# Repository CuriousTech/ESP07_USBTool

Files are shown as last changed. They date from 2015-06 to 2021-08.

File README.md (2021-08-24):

# ESP07_USBTool
3-in-1 board for ESP-07/12

[Clone from BangGood using spring clips](https://www.banggood.com/ESP8266-Test-Board-Burner-Development-Board-WIFI-Module-For-ESP-01-ESP-01S-ESP-12E-ESP-12F-ESP-12S-ESP-18T-p-1684992.html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)

USB powered with FTDI for programming and testing.  
Leave the FTDI and supporting components off for standalone USB 5V powered or 3.5-6V using pads on bottom rear.  
Use as serial+3V3 breakout with 0.1" pads for header on top rear of board.  
  
Rev 1.  Pogo pins are optional.  Outer 4 pinholes are for hold downs and should be done last for adjusting.  Get the height of the outer pins above inner, but only less that the size of the PCB.  
  
deepSleep is the R9 resistor  
run is R10   

esp07tool  

For more on the pogo-pins.  Lineup was done using all 3 PCBs and spacers.  Paste on top and heatgun.  

tool pogos

tool pogos 2

tool pogos 3

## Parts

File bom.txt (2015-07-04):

3V3R    MCP1824ST-3302E/DB (6V 300mA 0.3Vdo)
        TC1262-3.3VDBTR (6V 500mA 0.3Vdo)
        MCP1755T-3302E/DC (16V 300mA 0.5Vdo)
        MIC2920A-3.3WS TR (26V 400mA 0.75Vdo) Change C1 to 10uF.

IC1     FT230X-SSOP16
R1,R2   27 0805
R3      10K 0805  (reset pullup, don't use with deepSleep)
R4      10K 0805  (CH_PD pullup)
R5-R8   330 0805
R9      1K or jump (deepSleep)
R10     1K or jump (RUN enable)
C1,C2   1uF 0805
C3,C4   0.1uF 0805
C5,C6   47pF 0805
FLASH,RESET 3x4x2mm SMD button (eBay)
USB f   10118193-0001LF
LEDs    4x 0805 any color
JP1,JP2, top serial BO  breakable header 18 pins 0.1" + 1 jumper
ESP-07  Anywhere
P50-E2  0.68mm pogo pins (20) (eBay)

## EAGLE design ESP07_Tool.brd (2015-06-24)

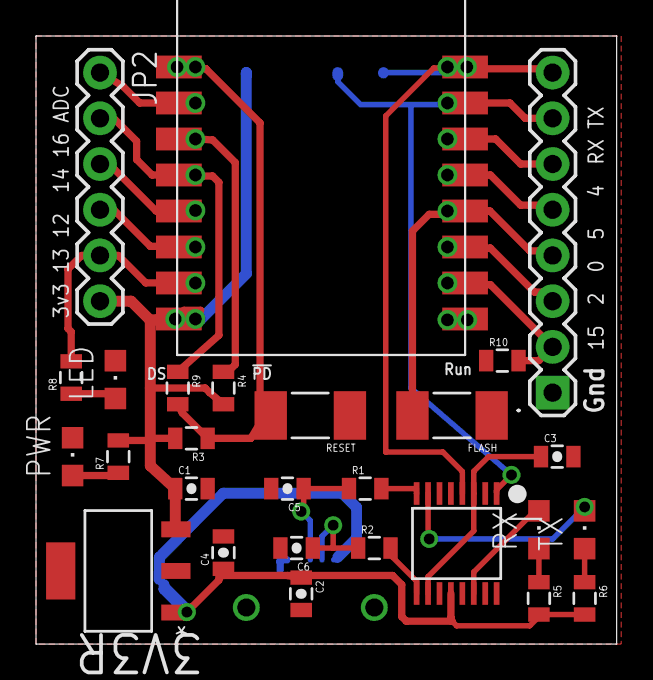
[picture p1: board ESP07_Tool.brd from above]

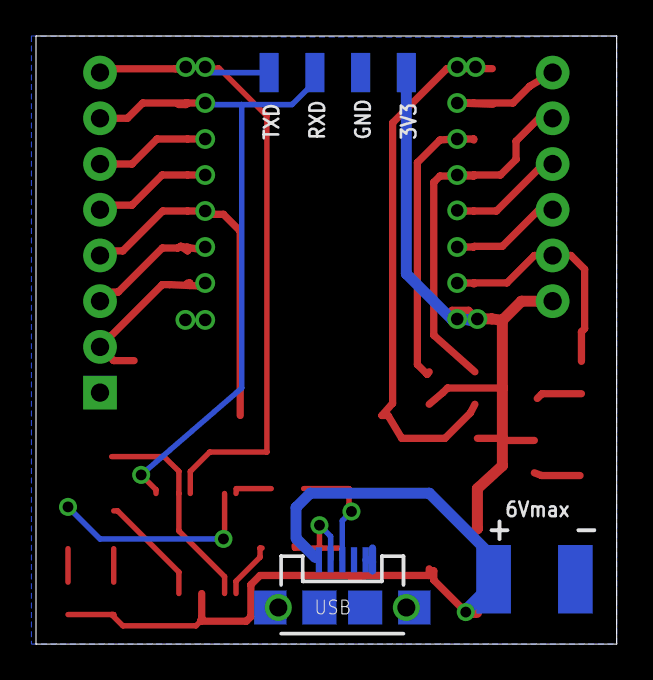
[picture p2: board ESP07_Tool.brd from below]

Board: 2 copper layers, 32.3 x 33.8 mm, 34 parts (7 on the bottom side), 28 nets.

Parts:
3V3R: MCP1824ST-3302E/DB; SOT230P700X180-4N
.: 1X08
C1, C2: 1uF; 0805-CAP
C3, C4: 0.1uF; 0805-CAP
C5, C6: 47pF; 0805-CAP
FLASH: R2010
JP2: 1X06
LED: CHIPLED_0805
PWR: CHIPLED_0805
R1, R2: 27; 0805
R3, R4, R9, R10: 10K; 0805
R5, R6, R7, R8: 330; 0805
RESET: R2010
RX: CHIPLED_0805
TX: CHIPLED_0805
U$1: ESP-07/12
U$2, U$3: SMD-PAD-SM; SMD-PAD3
U$4, U$5, U$6, U$7: SMD-PAD1
USB: USB-MICROB
|: IC_FT230X-SSOP-16; SSOP-16-FTDI

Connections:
3V3: 3V3R.3, C1.1, JP2.6, R3.2, R4.2, R7.2, U$1.VCC, U$6.>NAME
GND: 3V3R.2, 3V3R.4, ..1, C1.2, C2.2, C3.2, C4.2, C5.2, C6.2, FLASH.1, LED.C, PWR.C, R10.1, RESET.1, U$1.GND, U$2.P$1, U$7.>NAME, USB.GND, USB.MT1, USB.MT2, |.5, |.13
unnamed: JP2.3, U$1.GPIO14
unnamed: LED.A, R8.1
unnamed: ..6, U$1.GPIO4
unnamed: PWR.A, R7.1
unnamed: C3.1, |.3, |.10
unnamed: TX.C, |.7
unnamed: ..3, U$1.GPIO2
unnamed: ..2, R10.2, U$1.GPIO15
unnamed: ..5, U$1.GPIO5
unnamed: ..4, FLASH.2, U$1.GPIO0
unnamed: R4.1, U$1.CH_PD
unnamed: JP2.1, U$1.ADC
unnamed: RX.C, |.14
unnamed: R5.1, RX.A
unnamed: JP2.2, R9.1, U$1.GPIO16
unnamed: JP2.4, U$1.GPIO12
unnamed: JP2.5, R8.2, U$1.GPIO13
unnamed: R6.1, TX.A
unnamed: R2.2, |.9
unnamed: R1.2, |.8
unnamed: R3.1, R9.2, RESET.2, U$1.REST
unnamed: C6.1, R2.1, USB.D-
unnamed: C5.1, R1.1, USB.D+
RXD: ..7, U$1.RXD, U$4.>NAME, |.1
TXD: ..8, U$1.TXD, U$5.>NAME, |.4
VCC: 3V3R.1, C2.1, C4.1, R5.2, R6.2, U$3.P$1, USB.VBUS, |.12

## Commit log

2015-06-20 Fixed pogo pin positions
    [ESP07_Tool.brd]
2015-06-20 Update for pogo changes
    [ESP07_Tool.sch]
2015-06-20 Moved pads in 13mm wide
    [ESP07_Tool.brd]
2015-06-20 Update just in case
    [ESP07_Tool.sch]
2015-06-21 Mods after actual use
    [ESP07_Tool.brd]
2015-06-21 Sync with .brd
    [ESP07_Tool.sch]
2015-06-22 Added 3v3 and gnd header pins
    [ESP07_Tool.brd]
2015-06-24 Switched to MCP1824ST-3302E/DB
    [ESP07_Tool.brd]
2015-07-04 Added more regulator options

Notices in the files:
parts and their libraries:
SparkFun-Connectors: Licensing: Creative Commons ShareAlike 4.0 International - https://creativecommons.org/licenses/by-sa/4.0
